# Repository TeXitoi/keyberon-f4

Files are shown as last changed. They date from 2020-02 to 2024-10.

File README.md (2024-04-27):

# Unsplitted ergo Keyberon 

## Presentation

A handwired unsplitted ergo keyboard. It uses
[keyberon](https://github.com/TeXitoi/keyberon) for its firmware.

The case is totally parametric: you can customize a lot of things, including:
 - number of rows
 - number of columns
 - number of thumb keys
 - angle between the two halves
 - column stagger

## Gallery

### First version

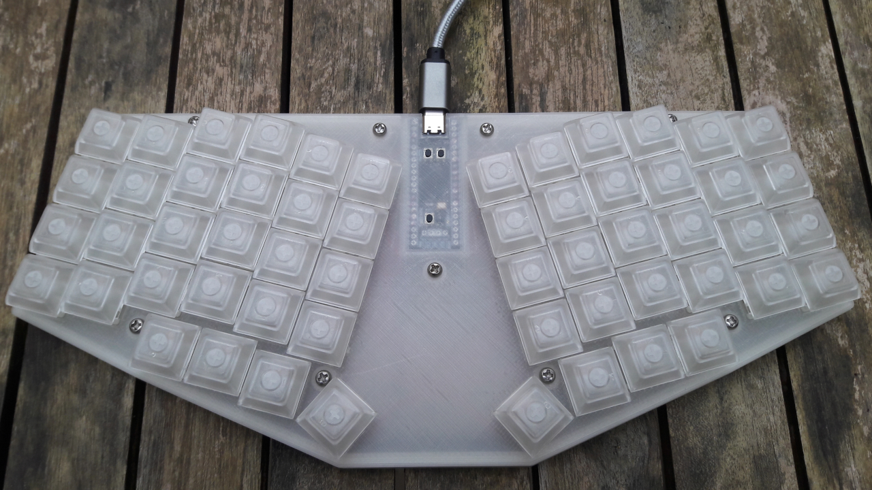
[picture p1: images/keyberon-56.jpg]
Keyberon 56


### Second version

The dev board has a dedicated cutout.

6×3+4 layout with a bit more stagger.

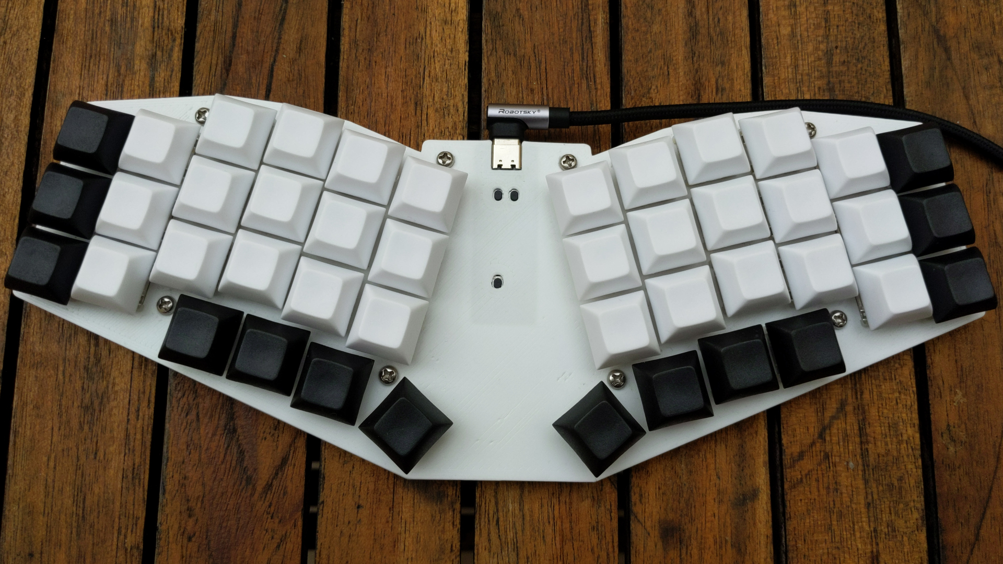
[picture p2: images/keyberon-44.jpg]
Keyberon 44


### Third version

The "plate" is now thick and play the role of case, with just a flat
sheet for the back.

Default version (6×3+4):

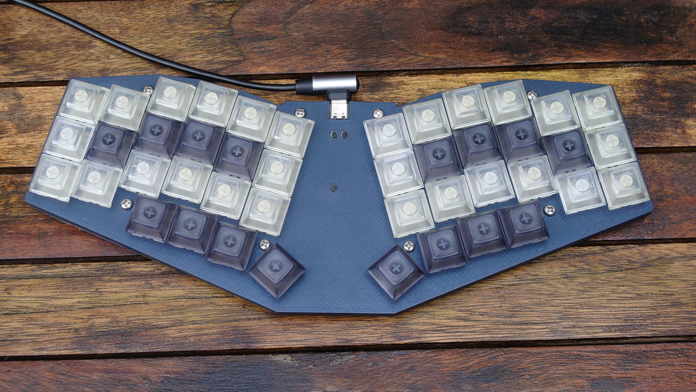
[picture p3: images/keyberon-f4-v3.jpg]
Keyberon v3


Minimal version, for testing, with
```
nb_cols=2;
nb_rows=2;
nb_thumbs=2;
```

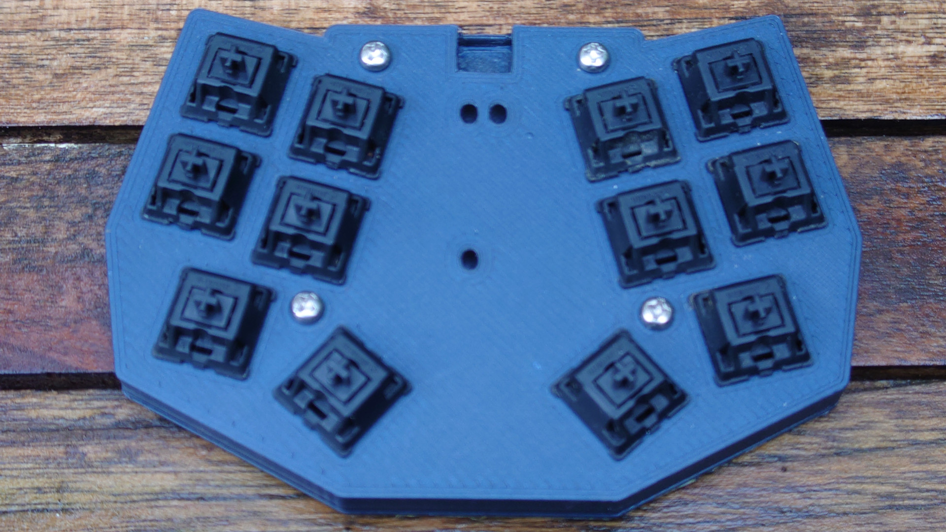
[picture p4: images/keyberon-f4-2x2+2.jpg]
Keyberon mini


### Fourth version

Choc height and spacing (optional), aligned thumb cluster (optional).

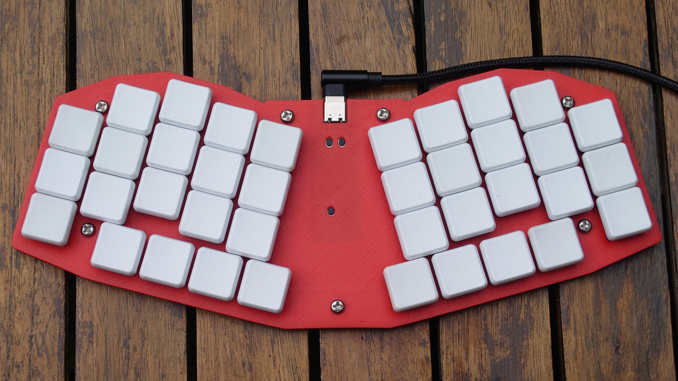
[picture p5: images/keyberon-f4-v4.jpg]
Keyberon v4


Side view, with choc switches on the left, and MX switches on the
right. 5 euro cent coin (21.25 mm of diameter) for scale.

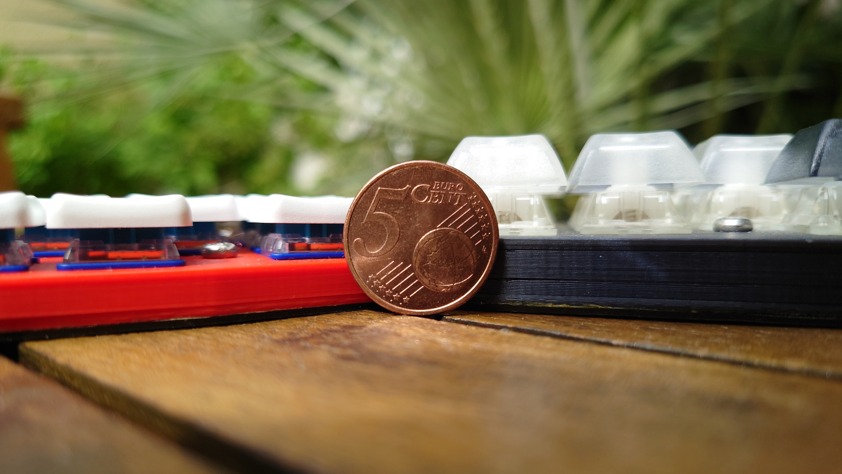
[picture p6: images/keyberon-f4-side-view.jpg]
Keyberon side view


I use this keyboard mostly over the laptop keyboard.

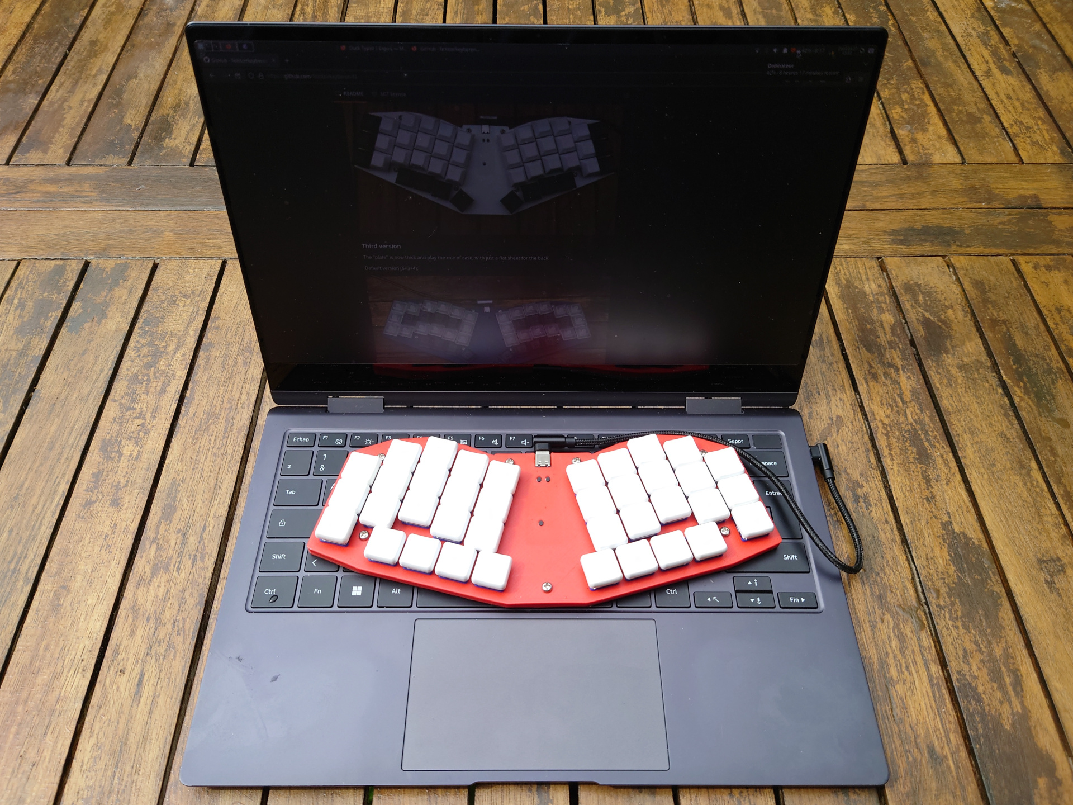
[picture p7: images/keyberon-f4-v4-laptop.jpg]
Keyberon over the laptop


## Bill of Materials

 - a [WeAct MiniF4 development board](https://www.aliexpress.com/item/1005001456186625.html)
 - a 3D printed [plate](cad/plate.stl)
 - a 3D printed [case](cad/case.stl)
 - 44 [Cherry MX compatible keyboard
   switches](https://www.aliexpress.com/item/32840007937.html) (for
   the default parameters)
 - 44 [Cherry MX compatible 1U
   keycaps](https://www.aliexpress.com/item/32830177884.html) (for the
   default parameters)
 - 44 [1N4148 diodes](https://www.aliexpress.com/item/32660088529.html)
   (for the default parameters)
 - [Polyurethane Enameled Copper Wire 0.2mm](https://www.aliexpress.com/item/1005003388771247.html)
 - 8 [4mm M3 screws](https://www.aliexpress.com/item/32948746653.html)
   (or 9 if you opt for center screw in the parameters)
 - 8 [3mm M3 brass inserts](https://www.aliexpress.com/item/32958273559.html)
   (or 9 if you opt for center screw in the parameters)
 - a [USB-C cable](https://www.aliexpress.com/item/4000624424432.html)
 - a [soldering kit](https://www.aliexpress.com/item/4000019437594.html)

Everything can be found for less than $60 new on Aliexpress without
the case.

## Building

You can follow the [building guide of keyberon
grid](https://github.com/TeXitoi/keyberon-grid/blob/master/BUILDING.md)
or any other handwiring guide. I recommand to read a few to have
different visions.

For the wiring of the dev board, refer to the source code for the pins.

## Compiling

Install the rust toolchain

```shell
curl https://sh.rustup.rs -sSf | sh
rustup target add thumbv7em-none-eabihf
rustup component add llvm-tools-preview
cargo install cargo-binutils
```

Compile the firmware

```shell
cargo objcopy --bin keyberon-f4 --release -- -O binary keyberon.bin
```

## Flashing using DFU

Put the developement board in DFU mode by pushing reset while pushing
boot, and then release boot. Then flash it:
```shell
dfu-util -w -d 0483:df11 -a 0 --dfuse-address 0x08000000:leave -D keyberon.bin
```

The LED on the board should react to caps lock (if you push caps lock
on another keyboard, the light should toggle), and the user button
send space.

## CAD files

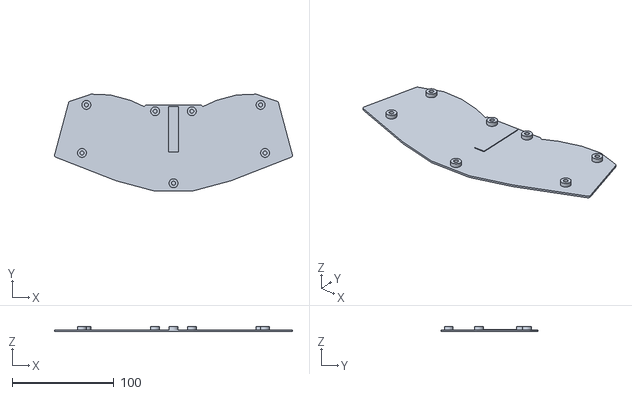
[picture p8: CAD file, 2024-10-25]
cad/case.stl
233.9 x 95.0 x 5.00

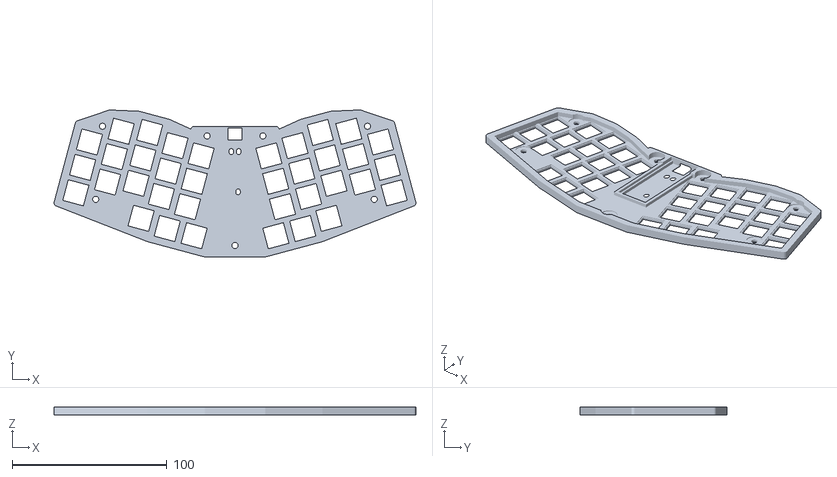
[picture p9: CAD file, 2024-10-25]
cad/plate.stl
233.9 x 95.0 x 5.00

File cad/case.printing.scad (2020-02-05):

use <plate.scad>
include <printing.scad>

case();

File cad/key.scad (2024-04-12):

use <utils.scad>

module keycap(choc=false) {
    translate([0,0,choc?4:5]) hull() {
        linear_extrude(0.1) square([choc?17.5:18.5, choc?16.5:18.5], center=true);
        translate([0, 0, choc?3:7.5]) linear_extrude(0.1) rounded_square(12, r=1.5, center=true);
    }
}

module switch(choc=false) {
    translate([0,0,choc?-2.2:-5]) linear_extrude(choc?3:6) rounded_square([13.5,13.5], r=1, center=true);
    linear_extrude(choc?3:6, scale=0.8) rounded_square([15, 15], r=1, center=true);
    translate([0,0,choc?-5:-8]) cylinder(h=5, d=4);
}

keycap();

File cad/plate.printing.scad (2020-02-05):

use <plate.scad>
include <printing.scad>

rotate([0, 180, 0]) plate();

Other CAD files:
cad/plate.scad
cad/printing.scad
cad/usb-c-pill.scad
cad/utils.scad

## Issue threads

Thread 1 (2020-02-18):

13th column in layout's first row

covah901, 2020-02-18:
src/main.rs

In the layout, I noticed the first row has a 13th column. First time submitting an issue, so not sure how to link directly to the file

TeXitoi, 2020-02-18:
That's a feature. The 13th column is the hardware button on the Dev board. As the button activate all the column, the others should be no action, and not having the value is equivalent to no action.

TeXitoi, 2020-02-18:
I'll add a comment explaining that layer on the source code before closing this issue.

covah901, 2020-02-19:
Thank you for explaining.

Closed 2020-03-11.

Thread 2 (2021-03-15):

PCB image

BoKKeR, 2021-03-15:
Could you provide a better image of the board for my site? https://keyb.io/parts/B08JvZqrS/Keyberon-f4

TeXitoi, 2023-11-03:
Hi.

Sorry for the delay. What's wrong with https://github.com/TeXitoi/keyberon-f4/raw/master/images/keyberon-44.jpg ?

BoKKeR, 2023-11-03:
The picture aspect was off and it’s a full keyboard. Not pcb only 😅

TeXitoi, 2023-11-03:
Mmm, so what can I do to help you?

BoKKeR, 2023-11-03:
Do you have a picture of the bare pcb by any chance ? No components soldered in

TeXitoi, 2023-11-03:
That's a handwired keyboard

BoKKeR, 2023-11-10:
Ah okay! My bad!

Closed 2023-11-10.

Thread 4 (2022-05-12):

Two keystokes registered on single button press

rurigk, 2022-05-12:
Hi, i'm using this as the base to build a custom keyboard but i'm having trouble with some weird behaviour

When i press any key of the columns 1, 2 or 3 the key below also get detected

If i bypass the diode the key works as expected

This is my schematic
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

I already check of shortcircuits, diode orientation

This is my second kb using keyberon but the other is using the bluepill (is using the same grid style)

Any idea why is happening? Thank you

dariogoetz, 2023-01-12:
When I had a similar issue with a blackpill based board running at 85 MHz, I could solve it by using the latest commit of keyberon (adds support for delays in the matrix scanning) and adding a short delay of 20us in the matrix scanning.

Maybe it's worth a try.

Closed 2023-11-03.

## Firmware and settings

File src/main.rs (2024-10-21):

#![no_main]
#![no_std]

// set the panic handler
use panic_halt as _;

use keyberon::debounce::Debouncer;
use keyberon::key_code::KbHidReport;
use keyberon::layout::Layout;
use keyberon::matrix::Matrix;
use rtic::app;
use stm32f4xx_hal::gpio::{self, AnyPin, Input, Output, PushPull};
use stm32f4xx_hal::otg_fs::{UsbBusType, USB};
use stm32f4xx_hal::prelude::*;
use stm32f4xx_hal::{pac, timer};
use usb_device::bus::UsbBusAllocator;
use usb_device::class::UsbClass as _;

mod layout;

type UsbClass = keyberon::Class<'static, UsbBusType, Leds>;
type UsbDevice = usb_device::device::UsbDevice<'static, UsbBusType>;

pub struct Leds {
    caps_lock: gpio::gpioc::PC13<gpio::Output<gpio::PushPull>>,
}
impl keyberon::keyboard::Leds for Leds {
    fn caps_lock(&mut self, status: bool) {
        if status {
            self.caps_lock.set_low()
        } else {
            self.caps_lock.set_high()
        }
    }
}

#[app(device = stm32f4xx_hal::pac, peripherals = true)]
mod app {
    use super::*;

    #[shared]
    struct Shared {
        usb_dev: UsbDevice,
        usb_class: UsbClass,
    }

    #[local]
    struct Local {
        matrix: Matrix<AnyPin<Input>, AnyPin<Output<PushPull>>, 13, 4>,
        debouncer: Debouncer<[[bool; 13]; 4]>,
        layout: Layout<12, 4, 4, ()>,
        timer: timer::CounterHz<pac::TIM3>,
    }

    #[init(local = [bus: Option<UsbBusAllocator<UsbBusType>> = None, ep_mem: [u32; 1024] = [0; 1024]])]
    fn init(c: init::Context) -> (Shared, Local, init::Monotonics) {
        let rcc = c.device.RCC.constrain();
        let clocks = rcc
            .cfgr
            .use_hse(25.MHz())
            .sysclk(84.MHz())
            .require_pll48clk()
            .freeze();
        let gpioa = c.device.GPIOA.split();
        let gpiob = c.device.GPIOB.split();
        let gpioc = c.device.GPIOC.split();

        let mut led = gpioc.pc13.into_push_pull_output();
        led.set_low();
        let leds = Leds { caps_lock: led };

        let usb = USB::new(
            (
                c.device.OTG_FS_GLOBAL,
                c.device.OTG_FS_DEVICE,
                c.device.OTG_FS_PWRCLK,
            ),
            (gpioa.pa11, gpioa.pa12),
            &clocks,
        );
        *c.local.bus = Some(UsbBusType::new(usb, c.local.ep_mem));
        let usb_bus = c.local.bus.as_ref().unwrap();

        let usb_class = keyberon::new_class(usb_bus, leds);
        let usb_dev = keyberon::new_device(usb_bus);

        let mut timer = timer::Timer::new(c.device.TIM3, &clocks).counter_hz();
        timer.start(1.kHz()).unwrap();
        timer.listen(timer::Event::Update);

        let Ok(matrix) = Matrix::new(
            [
                gpiob.pb14.into_pull_up_input().erase(),
                gpiob.pb15.into_pull_up_input().erase(),
                gpiob.pb5.into_pull_up_input().erase(),
                gpiob.pb6.into_pull_up_input().erase(),
                gpiob.pb7.into_pull_up_input().erase(),
                gpiob.pb8.into_pull_up_input().erase(),
                gpioa.pa5.into_pull_up_input().erase(),
                gpioa.pa6.into_pull_up_input().erase(),
                gpioa.pa7.into_pull_up_input().erase(),
                gpiob.pb0.into_pull_up_input().erase(),
                gpiob.pb1.into_pull_up_input().erase(),
                gpiob.pb10.into_pull_up_input().erase(),
                gpioa.pa0.into_pull_up_input().erase(),
            ],
            [
                gpioa.pa3.into_push_pull_output().erase(),
                gpioa.pa2.into_push_pull_output().erase(),
                gpioa.pa1.into_push_pull_output().erase(),
                gpiob.pb9.into_push_pull_output().erase(),
            ],
        );

        (
            Shared { usb_dev, usb_class },
            Local {
                timer,
                debouncer: Debouncer::new([[false; 13]; 4], [[false; 13]; 4], 5),
                matrix: matrix,
                layout: Layout::new(&crate::layout::LAYERS),
            },
            init::Monotonics(),
        )
    }

    #[task(binds = OTG_FS, priority = 2, shared = [usb_dev, usb_class])]
    fn usb_tx(c: usb_tx::Context) {
        (c.shared.usb_dev, c.shared.usb_class).lock(|usb_dev, usb_class| {
            if usb_dev.poll(&mut [usb_class]) {
                usb_class.poll();
            }
        })
    }

    #[task(binds = TIM3, priority = 1, shared = [usb_class], local = [matrix, debouncer, layout, timer])]
    fn tick(mut c: tick::Context) {
        c.local.timer.clear_flags(timer::Flag::Update);

        let Ok(matrix) = c.local.matrix.get();
        for event in c.local.debouncer.events(matrix) {
            c.local.layout.event(event);
        }
        match c.local.layout.tick() {
            keyberon::layout::CustomEvent::Release(()) => unsafe {
                cortex_m::asm::bootload(0x1FFF0000 as _)
            },
            _ => (),
        }

        let report: KbHidReport = c.local.layout.keycodes().collect();
        if c.shared
            .usb_class
            .lock(|k| k.device_mut().set_keyboard_report(report.clone()))
        {
            while let Ok(0) = c.shared.usb_class.lock(|k| k.write(report.as_bytes())) {}
        }
    }
}

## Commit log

2020-02-08 last corrections before the first real print
    [case.stl, plate.scad, plate.stl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]
2020-02-08 cargo update + pin for the complete keyboard
2020-02-15 Update to stm32f401 PR
2020-02-18 switch to official stm32f4xx-hal git version
2020-03-11 Add a comment explaining the 13th column
    fixes #1
    [main.rs]
2020-10-25 recessed USB connector
    [case.stl, plate.scad, plate.stl]
2020-10-25 fix borders
    [case.stl, plate.scad, plate.stl]
2020-10-28 more parametric
    [case.stl, plate.scad, plate.stl]
2020-11-08 small ajustment of usb c pill user button switch hole
    [case.stl, plate.stl, usb-c-pill.scad]
2021-04-30 small tweeks
    [case.stl, plate.scad, plate.stl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]
2021-10-18 Dedicated layout.rs file + bootloader instead of reset
    [main.rs]
2021-10-26 update stm32f4xx-hal
2023-11-04 Thick plate for surdity
    [case.stl, plate.scad, plate.stl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]
2024-01-18 Plate is the case, case is just the bottom
    [plate.scad]
2024-01-19 update stl
    [case.stl, plate.stl]
2024-01-30 Improve gallery
    [plate.scad]
2024-04-12 choc compat
    [key.scad, plate.scad]
2024-04-12 Aligned thumbs
    [plate.scad]
2024-10-25 fix unused variables
    [plate.scad]
2024-10-25 Proper choc outline
    [case.stl, plate.scad, plate.stl]
2024-10-25 center screw placement computation
    [case.stl, plate.scad, plate.stl]
